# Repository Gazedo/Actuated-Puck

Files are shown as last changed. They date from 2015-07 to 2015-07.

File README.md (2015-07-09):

# Actuated-Puck

## How To Connect and Command
 1. In order to connect to the puck you must have a bluetooth serial console.
 2. After installing a serial console such as putty, connect to the puck via bluetooth.
   * It will be called BT-42
   * If asked for a passcode try either 0000 or 1234, 0000 worked for me but in reality the puck doesn't have a security passphase so either should work.
 3. From there the command set is a set of 4 digits. The first digit is a switch variable and the last 3 are the command digits. The possible combinations are:
   * s000
Sets a new degree for the Set point for the PID algorithm.
In order to set for -10 degrees, command s350.
10 degrees would be s010.
   * p000
this would set the p variable to 0, in order to set the p variable to 5, command p500 as the number will be divided by 100.
  * i000
Same as the p variable but for the integral constant.
  * d000
Same as the p variable but for the derivative constant.
  * where the 000 is any possible combination of 3 digits.
 4. There will never be any feedback from the puck as the transmit line of the UART port is used to feed information to the sd card.

## Planned upgrades
Teensy 3.1
  * Would eliminate the 5V regulator and the 3V3 regulator.
  * Enable the chip to output the logged information by bluetooth rather than having to use the sd card
  * Operates at 3V3 but is tolerant to 5V
    * Would eliminate the need for the level shifter
9 DoF IMU
  * Doesn't seem to be needed under testing however it is an option if excessive yaw drift is found which effects the readings.
##Driver Chip
  * This driver chip (L6234) needs a very specialized commutation sequence in order to make the motor move and that code has been the major obstacle but there don't seem to be any better options on the market. An ideal chip would take the hall effect signals as input, a pwm signal from the MCU as input, and output the correct drive current and voltage.

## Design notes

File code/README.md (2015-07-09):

#Code Index
Use MIMEProject_r3.ino for testing as it is the most current.
Revision 2 uses interupts in order to spin the motor which works fine after the motor is initially spinning.

The libraries included are required for compiling the code, refer to arduino's how to in order to install them.
The code is made for a Teensy 2.0 and uses C++ language specific to that hardware. In order to port that hardware the code would need to be translated back to using Arduino's functions.

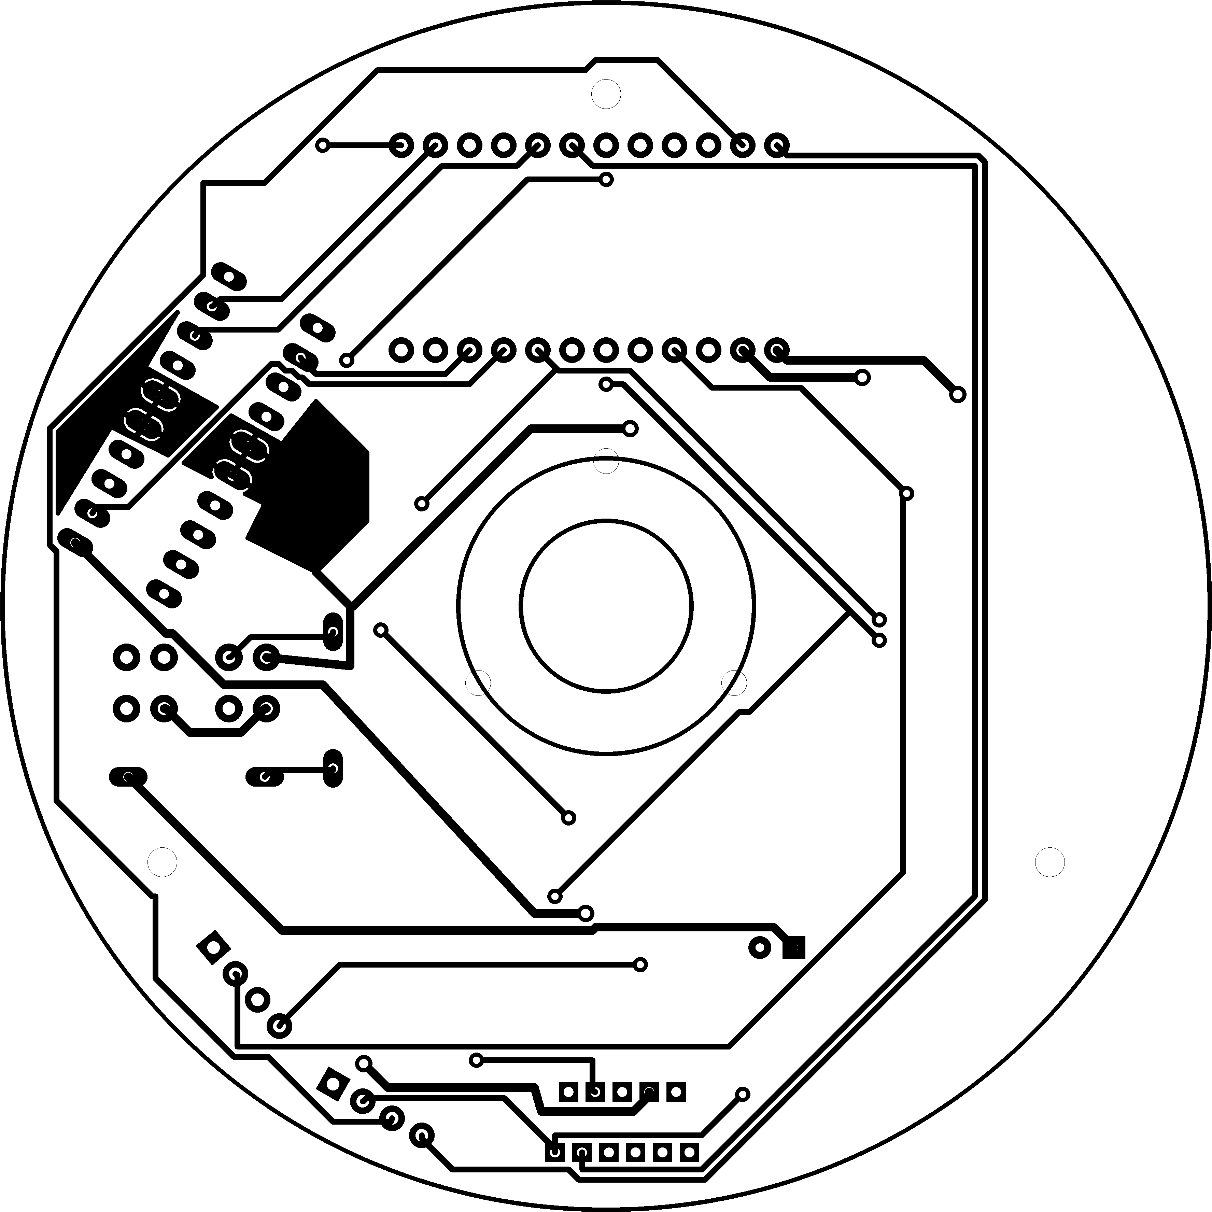
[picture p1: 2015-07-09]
eagle/r2/puck base.png

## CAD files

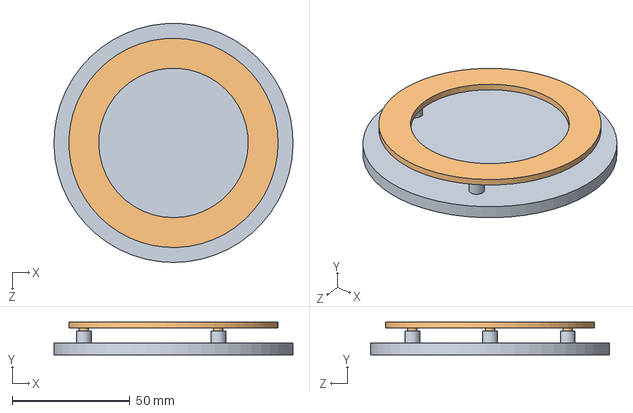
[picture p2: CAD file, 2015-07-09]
cad/Solid Works/Puck.SLDASM
101.6 x 14.0 x 101.5 mm
Puck_Base
Puck_Top

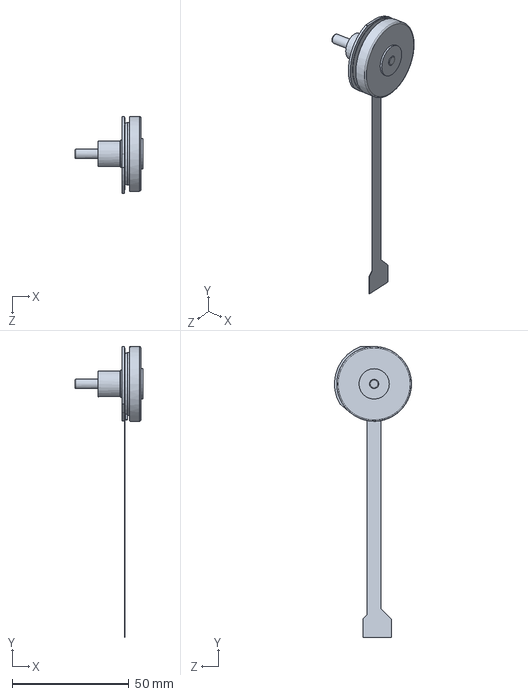
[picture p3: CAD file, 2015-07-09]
cad/Solid Works/5-13/EC32fl-200187.SLDPRT
29.3 x 124.5 x 33.0 mm

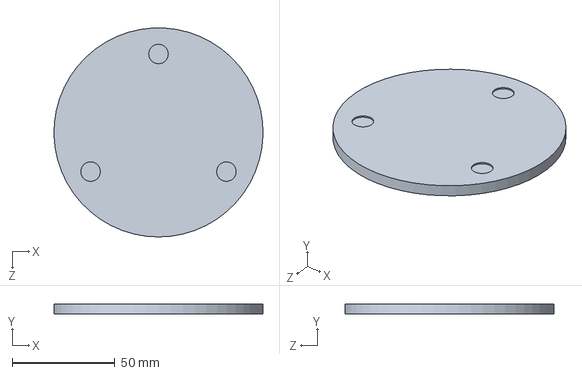
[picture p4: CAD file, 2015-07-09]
cad/Solid Works/5-27/5-27 p_g/Puck_Base.SLDPRT
101.6 x 5.08 x 101.5 mm

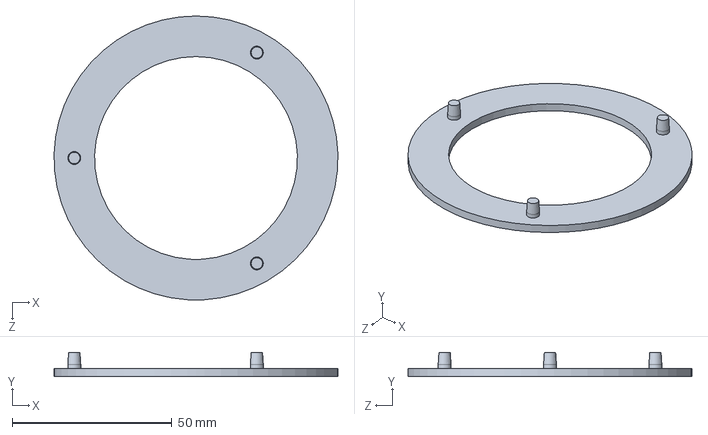
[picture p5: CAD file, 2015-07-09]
cad/Solid Works/Puck_Top.SLDPRT
88.9 x 7.62 x 88.9 mm

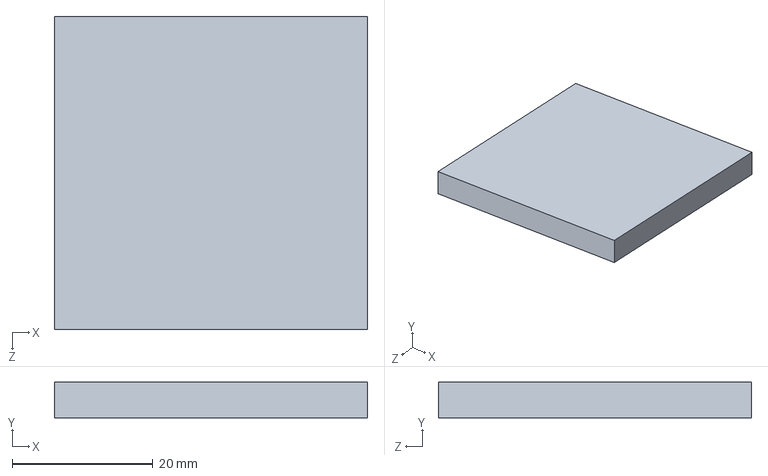
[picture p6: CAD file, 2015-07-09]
cad/Solid Works/5-13/controls subsys.SLDPRT
44.5 x 5.08 x 44.5 mm

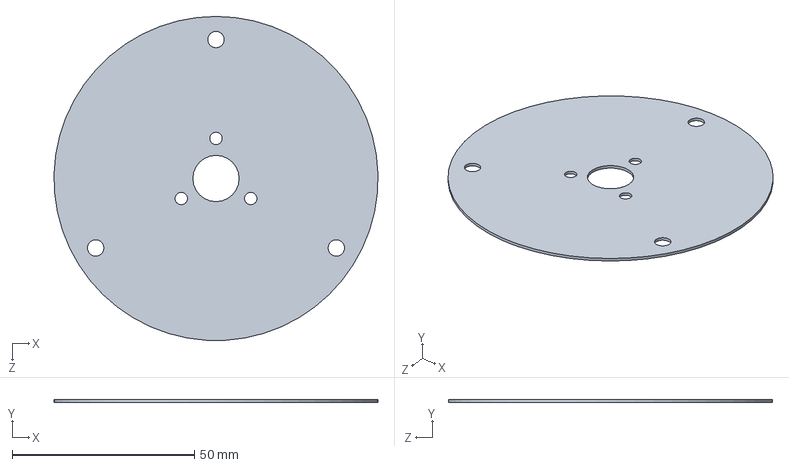
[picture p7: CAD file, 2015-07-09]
cad/Solid Works/5-27/5-27 p_g/Puck_Top.SLDPRT
88.9 x 0.8 x 88.9 mm

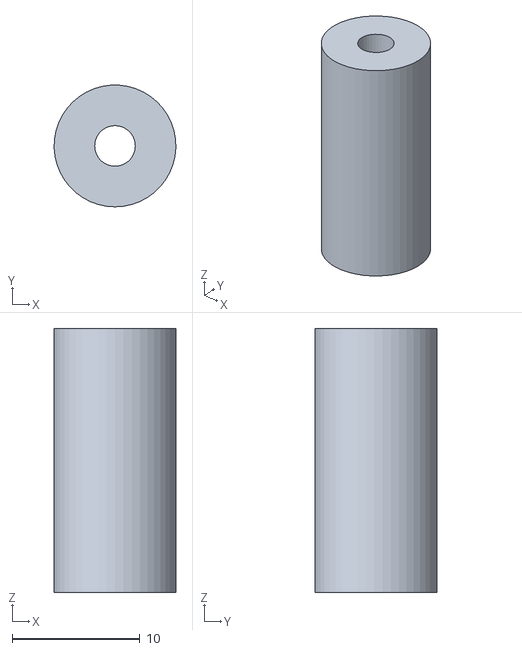
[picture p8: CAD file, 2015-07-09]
cad/Solid Works/5-27/standoff.STL
9.52 x 9.51 x 20.6

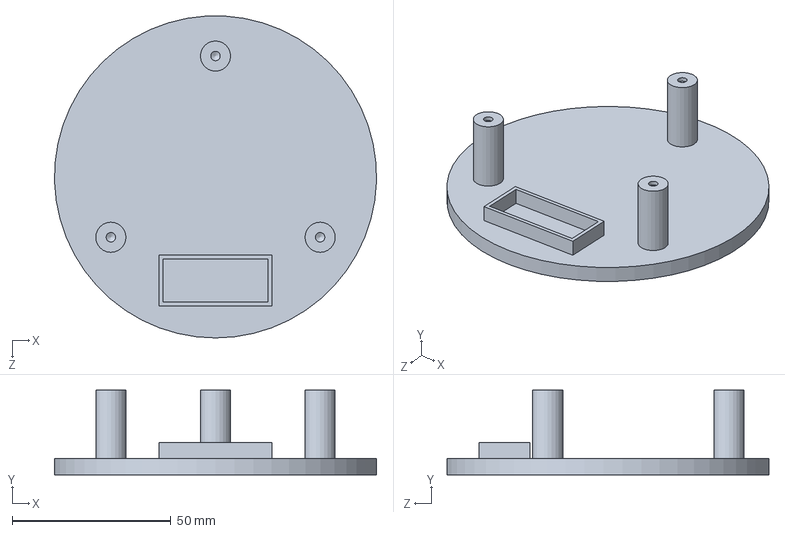
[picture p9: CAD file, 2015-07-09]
cad/Solid Works/5-13/Puck_Base.SLDPRT
101.6 x 26.7 x 101.5 mm

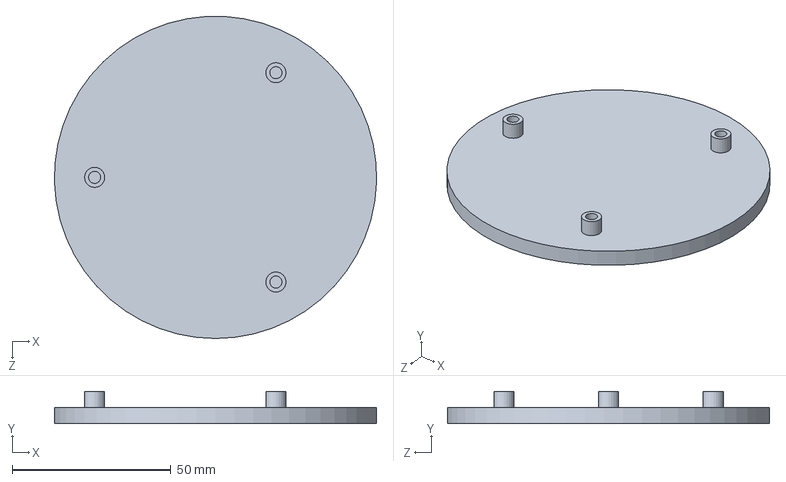
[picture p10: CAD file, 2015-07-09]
cad/Solid Works/Puck_Base.SLDPRT
101.6 x 10.2 x 101.5 mm

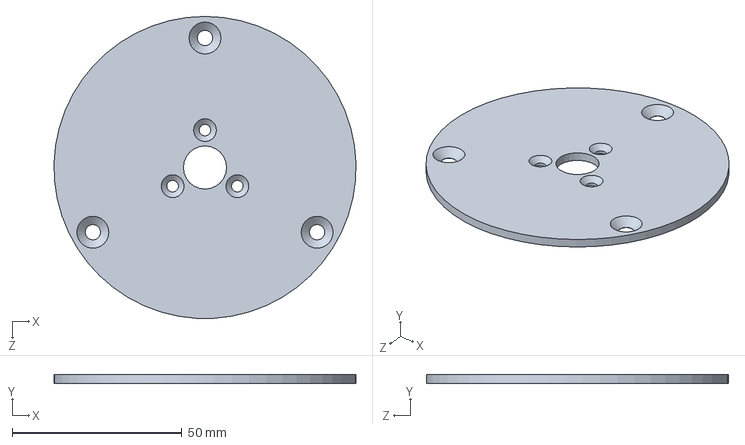
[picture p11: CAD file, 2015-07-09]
cad/Solid Works/5-13/Puck_Top.SLDPRT
88.9 x 2.54 x 88.9 mm

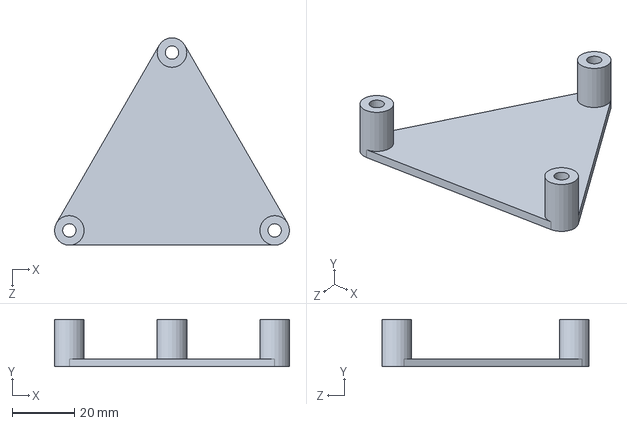
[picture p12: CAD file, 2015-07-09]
cad/Solid Works/5-27/5-27 p_g/pin plate.SLDPRT
75.5 x 15.2 x 66.7 mm

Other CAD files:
cad/Solid Works/5-27/Puck_Base.STL
cad/Solid Works/5-27/5-27 p_g/standoff.SLDPRT

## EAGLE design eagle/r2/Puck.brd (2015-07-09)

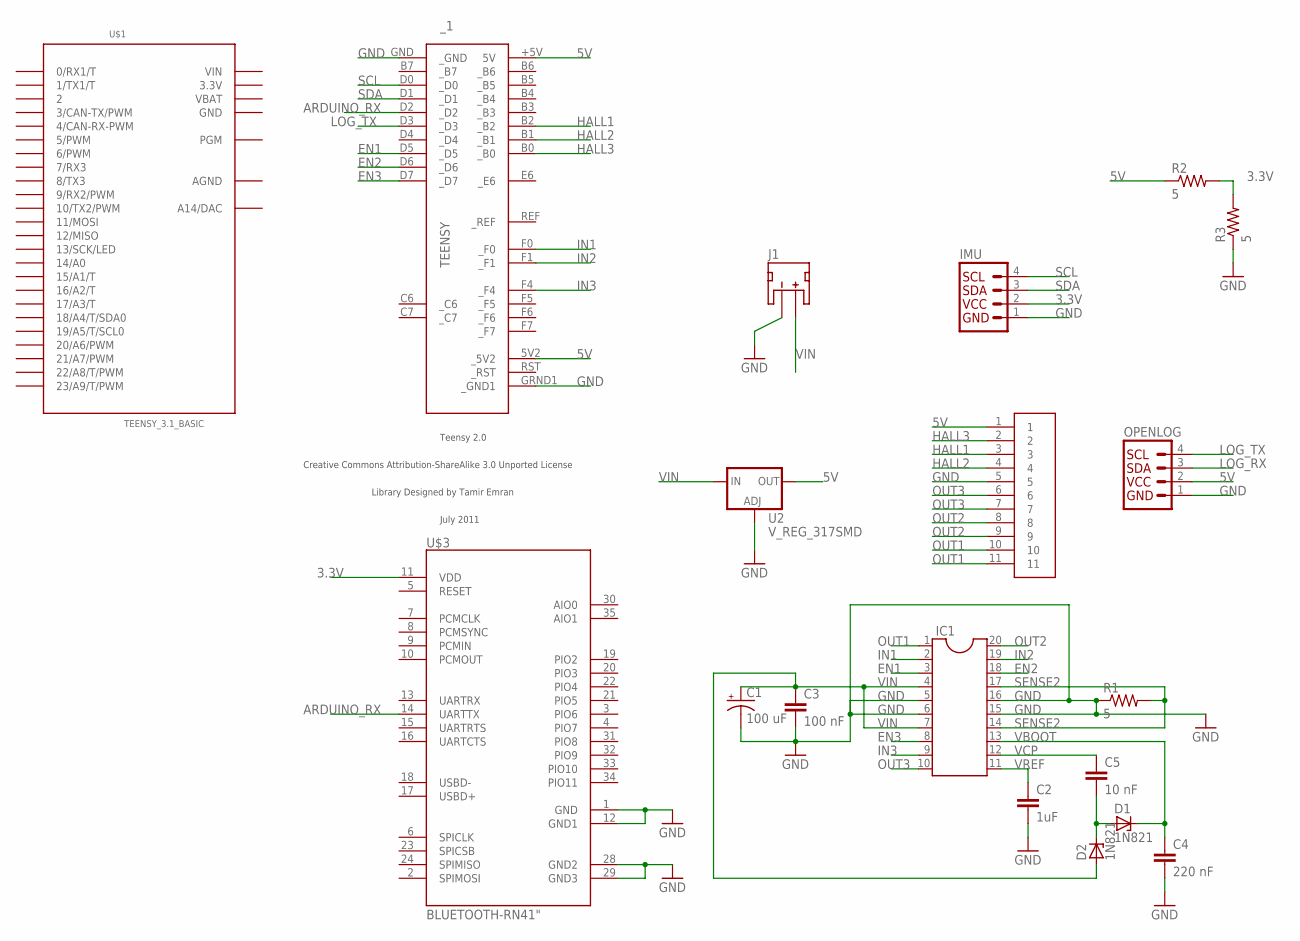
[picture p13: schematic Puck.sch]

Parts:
C1: 100 uF; CPOL-RADIAL-100UF-25V
C2: 1uF; CAP-PTH-SMALL-KIT
C3: 100 nF; CAP-PTH-SMALL-KIT
C4: 220 nF; CAP-PTH-SMALL-KIT
C5: 10 nF; CAP-PTH-SMALL-KIT
D1, D2: 1N821; DO35Z10
IC1: DIL20S; SOCKET-20
IMU: I2C_STANDARD; 1X04; MPN BIM-AKT-Y1X-0.4M-RS4.21T/S561
J1: JST_2MM_MALE; JST-2-SMD
MOLEX_MOTOR1: DEV; 52089FFCPACKAGE
OPENLOG: I2C_STANDARD; 1X04; MPN BIM-AKT-Y1X-0.4M-RS4.21T/S561
R1, R2, R3: 5; AXIAL-0.3
U2: V_REG_317SMD; SOT223
U$1: TEENSY_3.1_BASIC
U$3: BLUETOOTH-RN41"; RN41
_1: TEENSY

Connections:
3.3V: IMU.2, R2.P$2 (2), R3.P$2 (2), U$1.3.3V, U$1.3.3V1 (3.3V), U$3.11 (VDD)
5V: MOLEX_MOTOR1.1, OPENLOG.2, R2.P$1 (1), U2.2 (OUT), _1.5V2 (_5V2), _1.+5V (5V)
AGND: U$1.AGND
ARDUINO_RX: U$3.14 (UARTTX), _1.D2 (_D2)
EN1: IC1.3, _1.D5 (_D5)
EN2: IC1.18, _1.D6 (_D6)
EN3: IC1.8, _1.D7 (_D7)
GND: C1.2 (-), C2.2, C3.2, C4.2, IC1.5, IC1.6, IC1.15, IC1.16, IMU.1, J1.1 (-), MOLEX_MOTOR1.5, OPENLOG.1, R1.P$1 (1), R3.P$1 (1), U2.1 (ADJ), U$1.GND, U$1.GND1 (GND), U$3.1 (GND), U$3.12 (GND1), U$3.28 (GND2), U$3.29 (GND3), _1.GND (_GND), _1.GRND1 (_GND1)
HALL1: MOLEX_MOTOR1.3, _1.B2 (_B2)
HALL2: MOLEX_MOTOR1.4, _1.B1 (_B1)
HALL3: MOLEX_MOTOR1.2, _1.B0 (_B0)
IN1: IC1.2, _1.F0 (_F0)
IN2: IC1.19, _1.F1 (_F1)
IN3: IC1.9, _1.F4 (_F4)
LOG_RX: OPENLOG.3
LOG_TX: OPENLOG.4, _1.D3 (_D3)
unnamed: C5.2, D1.A, D2.C
OUT1: IC1.1, MOLEX_MOTOR1.10, MOLEX_MOTOR1.11
OUT2: IC1.20, MOLEX_MOTOR1.8, MOLEX_MOTOR1.9
OUT3: IC1.10, MOLEX_MOTOR1.6, MOLEX_MOTOR1.7
SCL: IMU.4, _1.D0 (_D0)
SDA: IMU.3, _1.D1 (_D1)
SENSE2: IC1.14, IC1.17, R1.P$2 (2)
VBAT: U$1.VBAT
VBOOT: C4.1, D1.C, IC1.13
VCP: C5.1, IC1.12
VIN: C1.1 (+), C3.1, D2.A, IC1.4, IC1.7, J1.2 (+), U2.3 (IN), U$1.VIN
VREF: C2.1, IC1.11

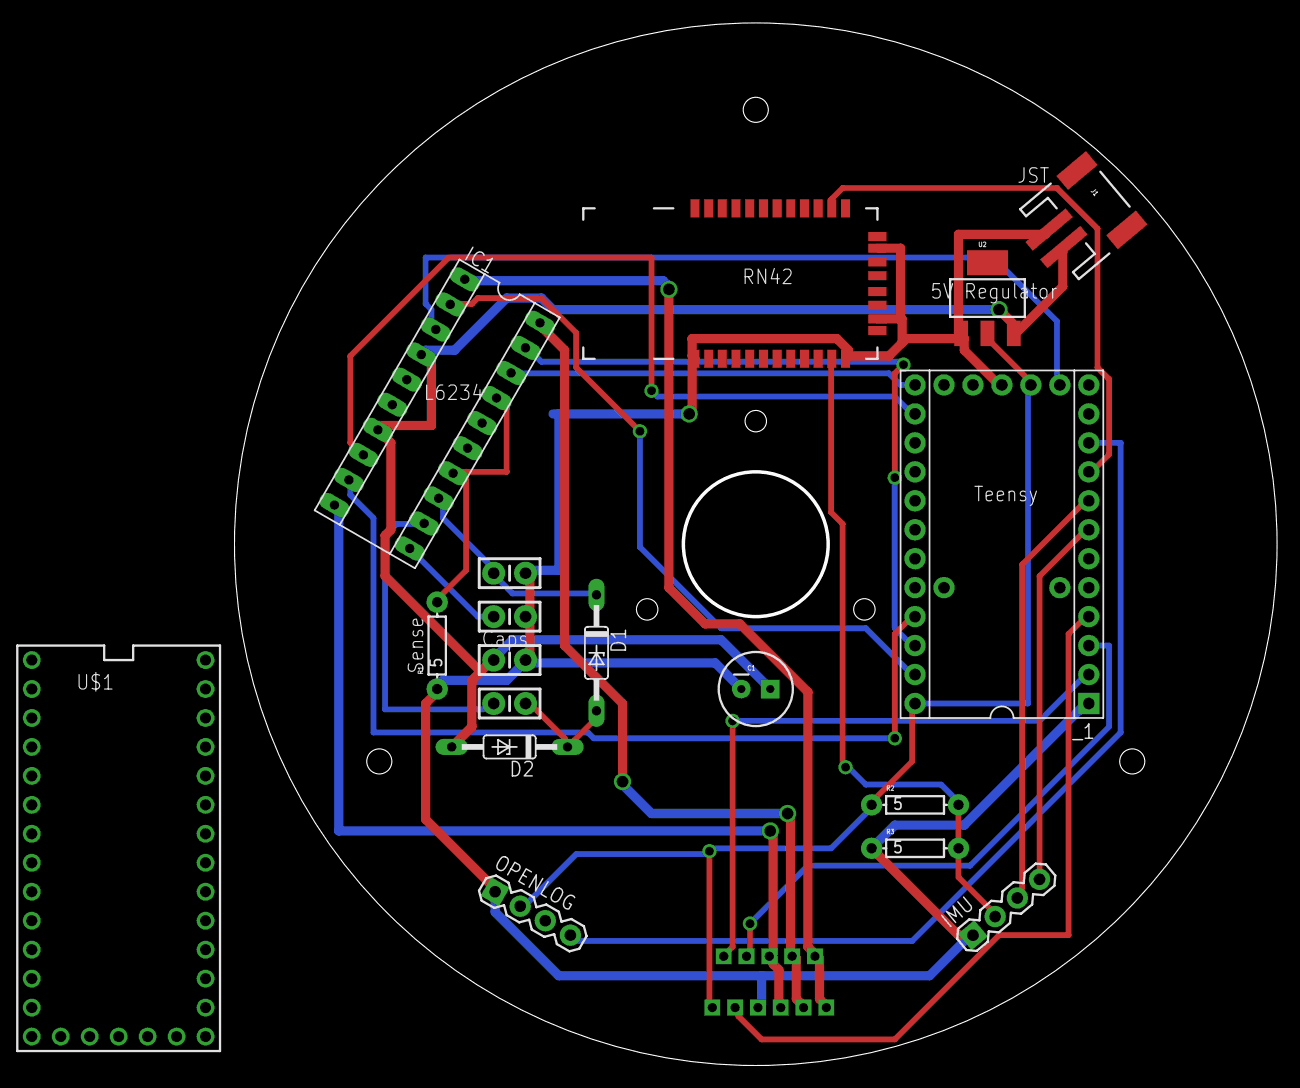
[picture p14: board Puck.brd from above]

Board: 2 copper layers, 91.4 x 91.4 mm, 19 parts (0 on the bottom side), 25 nets.

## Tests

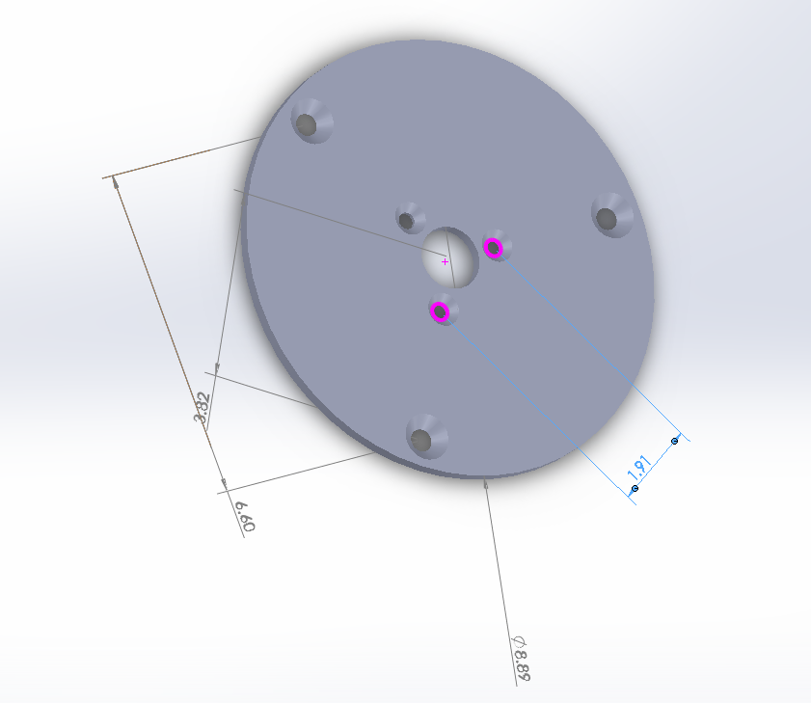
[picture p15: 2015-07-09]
eagle/r2/measurements.png

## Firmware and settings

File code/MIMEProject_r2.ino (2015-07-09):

#include <vector_math.h>
#include <CommunicationUtils.h>
#include <FreeIMU.h>
#include <calibration.h>

//FreeIMU stuff
#include <EEPROM.h>
#include <ADXL345.h>
#include <ITG3200.h>
#include <Wire.h>
#include <I2Cdev.h>
#include <SPI.h>
#include <DebugUtils.h>
//PID Library
#include <PID_v1.h>
//AVR stuff for change interupts
#include <avr/io.h>
#include <avr/interrupt.h>
//FreeIMU
//IMU declarations
FreeIMU imu = FreeIMU();
float vals[6];
double alpha, omega, theta;
double alpha_old, omega_old, theta_old;
char dec, Select;
//PID stuff
int time = 0, oldtime = 0, dt = 0;
double Setpoint = 0.00, Input = 0, Output;
double Kp = 0.5, Kd = 0.00, Ki = 0.00;
PID pid(&Input, &Output, &Setpoint, Kp, Kd, Ki, DIRECT);
volatile int hall = 0;
volatile int spd; // -255 up to 255, negative signifies reverse

//PWM motor pins
int Motor1in = 21, Motor2in = 20, Motor3in = 19;
//Enable pins
int Motor1en = 10, Motor2en = 11, Motor3en = 12;//pin 10 actually actautes pin 23
//Hall interrupt and read pins
int Hall1read = 0, Hall2read = 1, Hall3read = 2;
volatile int timeint = 0
void setup() {
  //Serial communication with openlog
  Serial.begin(9600);
  Serial1.begin(9600);
  Wire.begin();
  //Pin definations
  pinMode(Motor1in, OUTPUT);
  pinMode(Motor2in, OUTPUT);
  pinMode(Motor3in, OUTPUT);
  pinMode(Motor1en, OUTPUT);
  pinMode(Motor2en, OUTPUT);
  pinMode(Motor3en, OUTPUT);
  //Setup AVR interupts
  PCICR |= (1 << 0);
  PCMSK0 |= (0x5);
  //setup hall input
  DDRB |= 0x7;
  PORTB |= 0x7;
  //Init the imu
  delay(100);
  imu.init();
  //Set mode on pid library
  pid.SetMode(AUTOMATIC);
  pid.SetOutputLimits(-255.00, 255.00);
  delay(100);
  interrupts();
}

void loop() {
  //Compute at 200 Hz
  time = millis();

  //In case motor gets stuck between commutation sequences, kill before motor driver death.
  if (time - timeint >= 50) {
    PORTF = 0x0;
    PORTD = 0x0;
    PORTC = 0x0;
  }
  if (time - oldtime >= 5) {
    Serial.print(time); Serial.print("  "); Serial.println(oldtime);
    imu.getValues(vals);
    noInterrupts();
    //Get current forces felt
    dt = time - oldtime;
    //Get only the z rotation velocity
    omega = vals[5];
    theta += ((omega + omega_old) / 2) * (dt / 1000.0);
    //Set up PID inputs for compute
    Input = theta;
    pid.Compute();
    spd = Output;
    omega_old = omega;
    oldtime = time;
    Serial1.print(time);
    //Record all current values
    for (int i = 0; i < 6; i++) {
      Serial1.print(vals[i], 4);
      Serial1.print('\t');
    }
    Serial1.println("");
    interrupts();
    PCIFR |= (1 << 0);
  }
  //Recieve Instructions in the form of a single character and 3 digit number for now.
  //Could upgrade
  if ( Serial1.available() >= 4 ) {
    Select = Serial1.read();
    dec = 0;
    for (int i = 100; i >= 1; i /= 10) {
      dec += (Serial1.read() - '0') * i;
    }
  }
  else if ( Serial1.available() < 4 ) {
    Serial1.flush(); // get rid of excess
  }
  //Decide on instructions
  switch (Select) {
  case 's':
    Setpoint = dec;
    break;
  case 'p':
    Kp = dec / 100;
    break;
  case 'd':
    Kd = dec / 100;
    break;
  case 'i':
    Ki = dec / 100;
    break;
  }
}

ISR(PCINT0_vect) {
  //Looks like a long ISR but only 1 case is run each time one of the hall pins change. The rest is a decision structure.
  timeint = millis();
  hall = PINB & 0000111;
  PORTF = 0x0;
  PORTD = 0x0;
  PORTC = 0x0

  if ( spd > 0 ) { //Forward
    switch (hall) {
    case 5: // 101
      analogWrite(Motor1en, spd);//spd
      analogWrite(Motor2en, 255);
      digitalWrite(Motor1in, HIGH);
      break;
    case 4: // 100
      analogWrite(Motor1en, spd);//spd
      analogWrite(Motor3en, 255);
      digitalWrite(Motor1in, HIGH);
      break;
    case 6: // 110
      analogWrite(Motor2en, spd);//spd
      analogWrite(Motor3en, 255);
      digitalWrite(Motor2in, HIGH);
      break;
    case 2: // 010
      analogWrite(Motor1en, 255);
      analogWrite(Motor2en, spd);//spd
      digitalWrite(Motor2in, HIGH);
      break;
    case 3: // 011
      analogWrite(Motor1en, 255);
      analogWrite(Motor3en, spd);//spd
      digitalWrite(Motor3in, HIGH);
      break;
    case 1: // 001
      analogWrite(Motor2en, 255);
      analogWrite(Motor3en, spd);//spd
      digitalWrite(Motor3in, HIGH);
      break;
    }
  }
  else { //Reverse
    switch (hall) {
    case 5: // 101
      analogWrite(Motor1en, spd);
      analogWrite(Motor2en, 255);//spd
      digitalWrite(Motor2in, HIGH);
      break;
    case 4: // 100 WRONG
      analogWrite(Motor1en, spd);
      analogWrite(Motor3en, 255);//spd
      digitalWrite(Motor3in, HIGH);
      break;
    case 6: // 110
      analogWrite(Motor2en, spd);
      analogWrite(Motor3en, 255);//spd
      digitalWrite(Motor3in, HIGH);
      break;
    case 2: // 010
      analogWrite(Motor1en, spd);//spd
      analogWrite(Motor2en, 255);
      digitalWrite(Motor1in, HIGH);
      break;
    case 3: // 011
      analogWrite(Motor1en, spd);//spd
      analogWrite(Motor3en, 255);
      digitalWrite(Motor1in, HIGH);
      break;
    case 1: // 001
      analogWrite(Motor2en, spd);//spd
      analogWrite(Motor3en, 255);
      digitalWrite(Motor2in, HIGH);
      break;
    }
  }
}

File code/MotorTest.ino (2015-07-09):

#include <avr/io.h>
#include <avr/interrupt.h>

int dec;
char Select, val;
volatile int hall = 0, timeint = 0;
volatile int spd; // -255 up to 255, negative signifies reverse

//PWM motor pins
int Motor1in = 21, Motor2in = 20, Motor3in = 19;
//Enable pins
int Motor1en = 10, Motor2en = 11, Motor3en = 12;
//Hall interrupt and read pins
int Hall1read = 0, Hall2read = 1, Hall3read = 2;
void setup(){
    Serial.begin(9600);
    pinMode(Motor1in, OUTPUT);
    pinMode(Motor2in, OUTPUT);
    pinMode(Motor3in, OUTPUT);
    pinMode(Motor1en, OUTPUT);
    pinMode(Motor2en, OUTPUT);
    pinMode(Motor3en, OUTPUT);
    PCICR |= (1<<0);
    PCMSK0 |= (0x5);
    spd = 0;
    DDRB = 0x7;
    PORTB = 0x7;
}

void loop() {
  //sei();
  //Serial.println("before");
  Serial.print(timeint);
//  if (millis() - timeint >= 250) {
//    Serial.write("turned off motor");
//      PORTF &= 0xF8;
//      PORTD &= 0x1F;
//      PORTC = 0x0;
//  }
  if( Serial.available() == 4 ) {
    Select = Serial.read();
    dec = 0;
    for (int i=100; i>=1; i/=10) {
      val = Serial.read() - '0';
      dec += (int)val * i;
    }
  }
  else if (Serial.available() < 4  || Serial.available() > 4) {
    while(Serial.available()){
      byte h = Serial.read();
    }
  }
  
  switch (Select) {
  case 'n':
    spd = -1*(int)dec;
    break;
  case 'p':
    spd = (int)dec;
    break;
  }
  delay(100);
  PCIFR |= (1 << 0);
  Serial.println(spd,DEC);
}

ISR(PCINT0_vect){
	PORTF &= 0xF8;
        PORTD &= 0x1F;
        PORTC = 0x0;
	hall = PINB & 0x7;
	if ( spd > 0 ){ //Forward
		switch (hall) {
			case 5: // 101
				digitalWrite(Motor1en, HIGH);
				digitalWrite(Motor2en, HIGH);
				analogWrite(Motor1in, spd);
				break;
			case 4: // 100
				digitalWrite(Motor1en, HIGH);
				digitalWrite(Motor3en, HIGH);
				analogWrite(Motor1in, spd);
				break;
			case 6: // 110
				digitalWrite(Motor2en, HIGH);
				digitalWrite(Motor3en, HIGH);
				analogWrite(Motor2in, spd);
				break;
			case 2: // 010
				digitalWrite(Motor1en, HIGH);
				digitalWrite(Motor2en, HIGH);
				analogWrite(Motor2in, spd);
				break;
			case 3: // 011
				digitalWrite(Motor1en, HIGH);
				digitalWrite(Motor3en, HIGH);
				analogWrite(Motor3in, spd);
				break;
			case 1: // 001
				digitalWrite(Motor2en, HIGH);
				digitalWrite(Motor3en, HIGH);
				analogWrite(Motor3in, spd);
				break;
		}
	}
	else{ //Reverse
		switch (hall) {
			case 5: // 101
				digitalWrite(Motor1en, HIGH);
				digitalWrite(Motor2en, HIGH);
				analogWrite(Motor2in, spd);
				break;
			case 4: // 100 WRONG
				digitalWrite(Motor1en, HIGH);
				digitalWrite(Motor3en, HIGH);
				analogWrite(Motor3in, spd);
				break;
			case 6: // 110
				digitalWrite(Motor2en, HIGH);
				digitalWrite(Motor3en, HIGH);
				analogWrite(Motor3in, spd);
				break;
			case 2: // 010
				digitalWrite(Motor1en, HIGH);
				digitalWrite(Motor2en, HIGH);
				analogWrite(Motor1in, spd);
				break;
			case 3: // 011
				digitalWrite(Motor1en, HIGH);
				digitalWrite(Motor3en, HIGH);
				analogWrite(Motor1in, spd);
				break;
			case 1: // 001  WRONG
				digitalWrite(Motor2en, HIGH);
				digitalWrite(Motor3en, HIGH);
				analogWrite(Motor2in, spd);
				break;
		}
	}
}

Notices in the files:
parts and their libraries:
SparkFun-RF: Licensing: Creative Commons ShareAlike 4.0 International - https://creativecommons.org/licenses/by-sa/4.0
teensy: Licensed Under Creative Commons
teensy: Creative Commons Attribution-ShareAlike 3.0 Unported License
